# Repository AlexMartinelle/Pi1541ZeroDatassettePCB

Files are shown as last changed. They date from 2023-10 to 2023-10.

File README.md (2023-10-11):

# Pi1541ZeroDatassettePCB
PCB design for a Pi11541 hat for the Raspberry Pi Zero with additional datassette IO support.

I wanted a Pi1541 hat for the Raspberry Pi Zero that had proper serial ports
and the pins to support my datassette support for the Pi1541.
Datasette code available at: https://github.com/AlexMartinelle/Pi1541DatassetteSupport

This PCB is designed to be used with the Pi1541 Option B settings but with one extra tweak,
the i2cBusMaster setting should be zero since it uses pin 27 for SDA, and pin 28 for SCL.

The gerbers are also available from PCBWay at https://www.pcbway.com/project/shareproject/Pi1541_option_B_hat_for_Raspberry_Pi_Zero_with_datassette_IO_support_94f0028b.html

The design is loosely based on the https://github.com/hackup/Pi1541io PCB and the components used on that PCB.

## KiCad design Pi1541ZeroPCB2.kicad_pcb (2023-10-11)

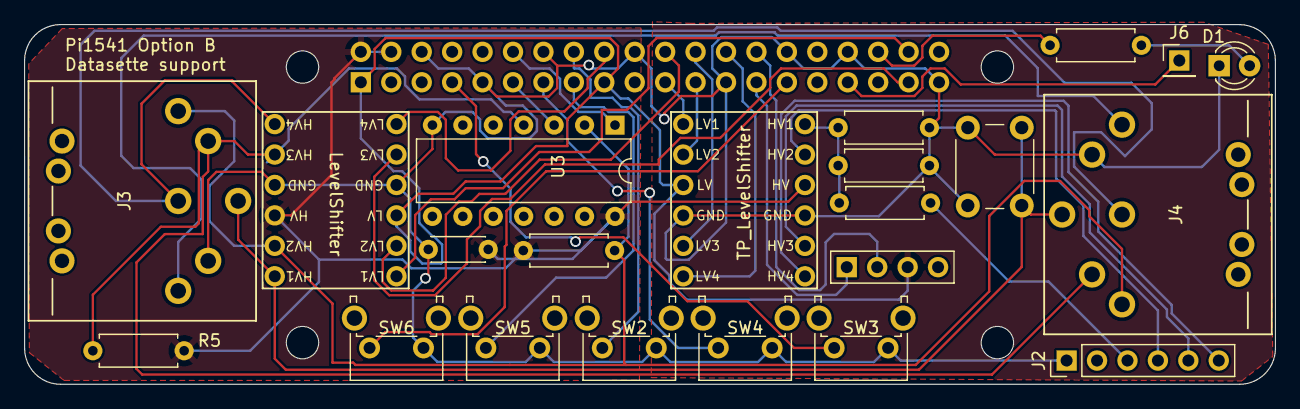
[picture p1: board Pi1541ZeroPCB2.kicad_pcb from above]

Board: 2 copper layers, 104.4 x 30.0 mm, 27 parts (1 on the bottom side), 33 nets.

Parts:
C1: 100n; C_Disc_D4.3mm_W1.9mm_P5.00mm
D1: ACT; LED_D3.0mm
J1: GPIO; PinSocket_2x20_P2.54mm_Vertical
J2: TP_PORT_C64; PinHeader_1x06_P2.54mm_Vertical
J3: IEC1; DIN-6-Variable
J4: IEC2; DIN-6-Variable
J5: I2C; Socket_Strip_Straight_1x04_Pitch2.54mm
J6: ExtSpkr; PinHeader_1x01_P2.54mm_Vertical
MH1, MH2, MH3, MH4: MountingHole_2.7mm_M2.5
R1: 1K; R_Axial_DIN0207_L6.3mm_D2.5mm_P7.62mm_Horizontal
R2: 4.7K; R_Axial_DIN0207_L6.3mm_D2.5mm_P7.62mm_Horizontal
R3, R6: 220; R_Axial_DIN0207_L6.3mm_D2.5mm_P7.62mm_Horizontal
R4, R5: 1k; R_Axial_DIN0207_L6.3mm_D2.5mm_P7.62mm_Horizontal
SW1: Reset; SW_PUSH_6mm
SW2: Next_Btn; SW_Tactile_SPST_Angled_PTS645Vx83-2LFS
SW3: Exit_Btn; SW_Tactile_SPST_Angled_PTS645Vx83-2LFS
SW4: Select_Btn; SW_Tactile_SPST_Angled_PTS645Vx83-2LFS
SW5: Prev_Btn; SW_Tactile_SPST_Angled_PTS645Vx83-2LFS
SW6: Insert_Btn; SW_Tactile_SPST_Angled_PTS645Vx83-2LFS
U1: TP_LevelShifter; LevelShifterModule4CH
U2: LevelShifter; LevelShifterModule4CH
U3: 7406; DIP-14_W7.62mm

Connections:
+3V3: J1.1, J1.17, J5.3, U1.3 (LV), U2.3 (LV)
+5V: C1.1, J1.2, J1.4, R4.1, R5.1, U1.10 (HV), U2.10 (HV), U3.14 (Vcc)
/GPIO4/GPCLK0: J1.7, SW3.2
/GPIO5: J1.29, SW6.2
/GPIO13/PWM1: J1.33, J6.1
/GPIO16: J1.36, R6.1
/GPIO22: J1.15, SW5.2
/GPIO23: J1.16, SW2.2
/GPIO27: J1.13, SW4.2
ATN: J3.3, J4.3, U2.7 (HV4)
ATN_IN: J1.18, U2.6 (LV4)
CLK: J3.4, J4.4, R5.2, U2.8 (HV3), U3.4
CLK_BD: J1.11, U3.3
CLK_IN: J1.37, U2.5 (LV3)
DATA: J3.5, J4.5, R4.2, U2.11 (HV2), U3.2
DATA_BD: J1.12, U3.1
DATA_IN: J1.22, U2.2 (LV2)
GND: C1.2, D1.1 (K), J1.6, J1.9, J1.14, J1.20, J1.25, J1.30, J1.34, J1.39, J2.1, J3.2, J4.2, J5.4, R1.2, R2.2, SW1.2, SW2.1, SW3.1, SW4.1, SW5.1, SW6.1, U1.4 (GND), U1.9 (GND), U2.4 (GND), U2.9 (GND), U3.7 (Gnd)
I2C0_SCL: J1.28, J5.2
I2C0_SDA: J1.27, J5.1
unnamed: D1.2 (A), R6.2
unnamed: J2.3, R3.1
RESET: J3.6, J4.6, SW1.1, U2.12 (HV1)
RESET_IN: J1.38, U2.1 (LV1)
SRQ: J3.1, J4.1
TP_MOTOR_3V: J1.21, U1.1 (LV1)
TP_MOTOR_6V: R1.1, R2.1, R3.2, U1.12 (HV1)
TP_READ_3V: J1.23, U1.2 (LV2)
TP_READ_5V: J2.4, U1.11 (HV2)
TP_SENSE_3V: J1.26, U1.6 (LV4)
TP_SENSE_5V: J2.6, U1.7 (HV4)
TP_WRITE_3V: J1.24, U1.5 (LV3)
TP_WRITE_5V: J2.5, U1.8 (HV3)
